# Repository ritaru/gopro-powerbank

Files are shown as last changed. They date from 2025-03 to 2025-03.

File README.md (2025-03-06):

## 5V 3A Capable Single 18650 Power Bank

The required components are as follows.

Parts are 2.0*1.2mm (2012 metric) if there is no further notation.

| Schematic Number | Value | Notes |
|:---:|:---:|:---:|
| BT1 / BT2 | Generic 18650 Holder | SMD / Through-Hole capable |
| U1 | TPS61022RWUR | Texas Instruments has the only capable IC |
| U2 | TP4056 | Generic TP4056 will work |
| U3 | S-8261 | DW01A also work |
| U4 | 8205A | Generic ones work |
| U5 | 8205A | Generic ones work |
| J1 | USB-C Receptacle | HRO Type, Recommending LCSC #C2765186 |
| R1 | 732k | Based on TPS61022 datasheet |
| R2 | 100k | Based on TPS61022 datasheet |
| R3 | 1.2k | Based on TP4056 datasheet |
| R4 | 1k | Based on TP4056 datasheet, decrease if not bright enough |
| R5 | 1k | Based on TP4056 datasheet, decrease if not bright enough |
| R6 | 1k | Based on DW01A datasheet, change if S-8261 is used |
| R7 | 100 | Based on DW01A datasheet, change if S-8261 is used |
| R8 | 5.1k | USB-C CC pin pull down |
| R9 | 5.1k | USB-C CC pin pull down |
| C1 | 10u / 10V | X5R, MLCC |
| C2 | 10u / 10V | X5R, MLCC |
| C3 | 0.1u / 50V | MLCC |
| C4 | 22u / 10V | X5R, MLCC |
| C5 | 22u / 10V | X5R, MLCC |
| C6 | 22u / 10V | X5R, MLCC |
| C7 | 0.1u / 50V | MLCC |
| C8 | 0.1u / 50V | MLCC |
| L1 | 1u | XAL7030-102MEC, TI reference design |
| D1 | Generic LED | STANDBY |
| D2 | Generic LED | CHARGING |
| D3 | TVS Diode | 5.6V Breakdown, SOD-323 |

## Side notes

- This is designed for Gopro Hero 9/10/11/12.
- Gopro Hero 9/10/11/12 requires a charger that is capable of delivering more than 10W(5V 2A) with no internal battery.
- I find this design to be also suitable for outdoor use when appropriate enclosure is added for a helmet mount.
- For copper weight on the PCB, it is 2oz minimum. (Due to limitation of L1 contacts on TPS61022)
- It automatically engages PFM(Pulse Frequency Modulation) when on low load. The MODE pin is pulled down.
- When not in use, please disconnect the battery. There is no onboard switch for on/off feature. (I might add this though)
- TP4056 happens to be quite hot when charging. Use separate charging tools (such as XTAR or Nitecore) for durability.
- I haven't built this yet, so additional features may be added later.

### AGPL v3.0 License
This repository is using AGPL v3.0.

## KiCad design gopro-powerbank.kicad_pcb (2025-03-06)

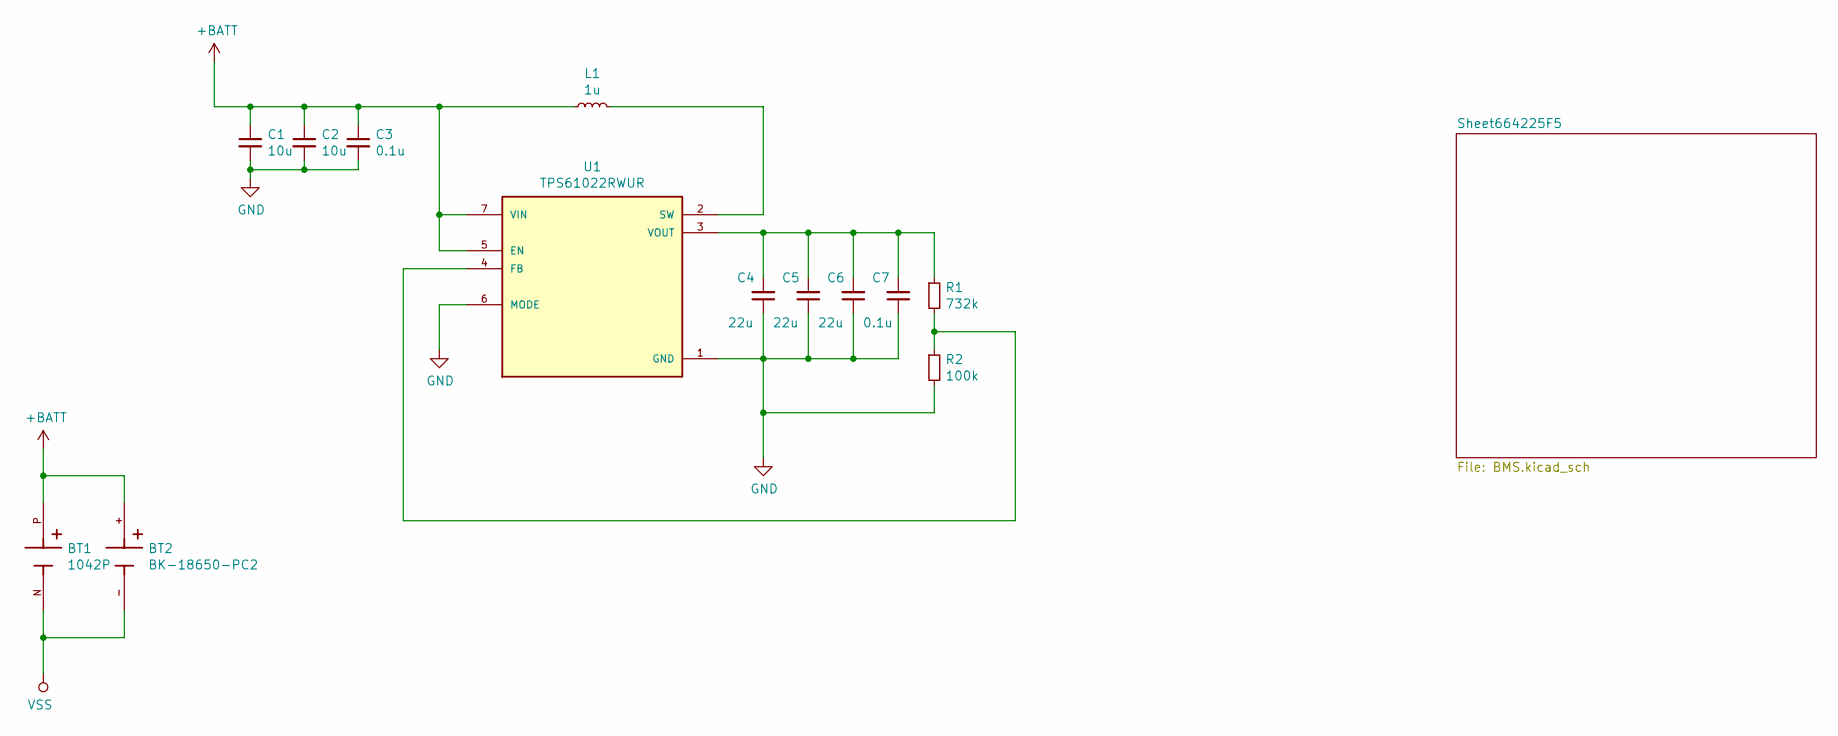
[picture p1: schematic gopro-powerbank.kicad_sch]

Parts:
BT1: 1042P; BAT_1042P; PARTREV E
BT2: BK-18650-PC2; BAT_BK-18650-PC2; PARTREV F
C1, C2: 10u; C_0805_2012Metric_Pad1.15x1.40mm_HandSolder
C3, C7: 0.1u; C_0805_2012Metric_Pad1.15x1.40mm_HandSolder
C4, C5, C6: 22u; C_0805_2012Metric_Pad1.15x1.40mm_HandSolder
L1: 1u; INDDFN750X750X310-2N
R1: 732k; R_0805_2012Metric_Pad1.15x1.40mm_HandSolder
R2: 100k; R_0805_2012Metric_Pad1.15x1.40mm_HandSolder
U1: TPS61022RWUR; CONV_TPS61022RWUR; PARTREV 4223724/C 02/2018

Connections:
+BATT: BT1.P, BT2.+, C1.1, C2.1, C3.1, L1.1, U1.5 (EN), U1.7 (VIN); also elsewhere on the board
GND: C1.2, C2.2, C3.2, C4.1, C5.1, C6.1, C7.1, R2.2, U1.1 (GND), U1.6 (MODE); also elsewhere on the board
unnamed: C4.2, C5.2, C6.2, C7.2, R1.1, U1.3 (VOUT)
unnamed: L1.2, U1.2 (SW)
unnamed: R1.2, R2.1, U1.4 (FB)
VSS: BT1.N, BT2.-; also elsewhere on the board

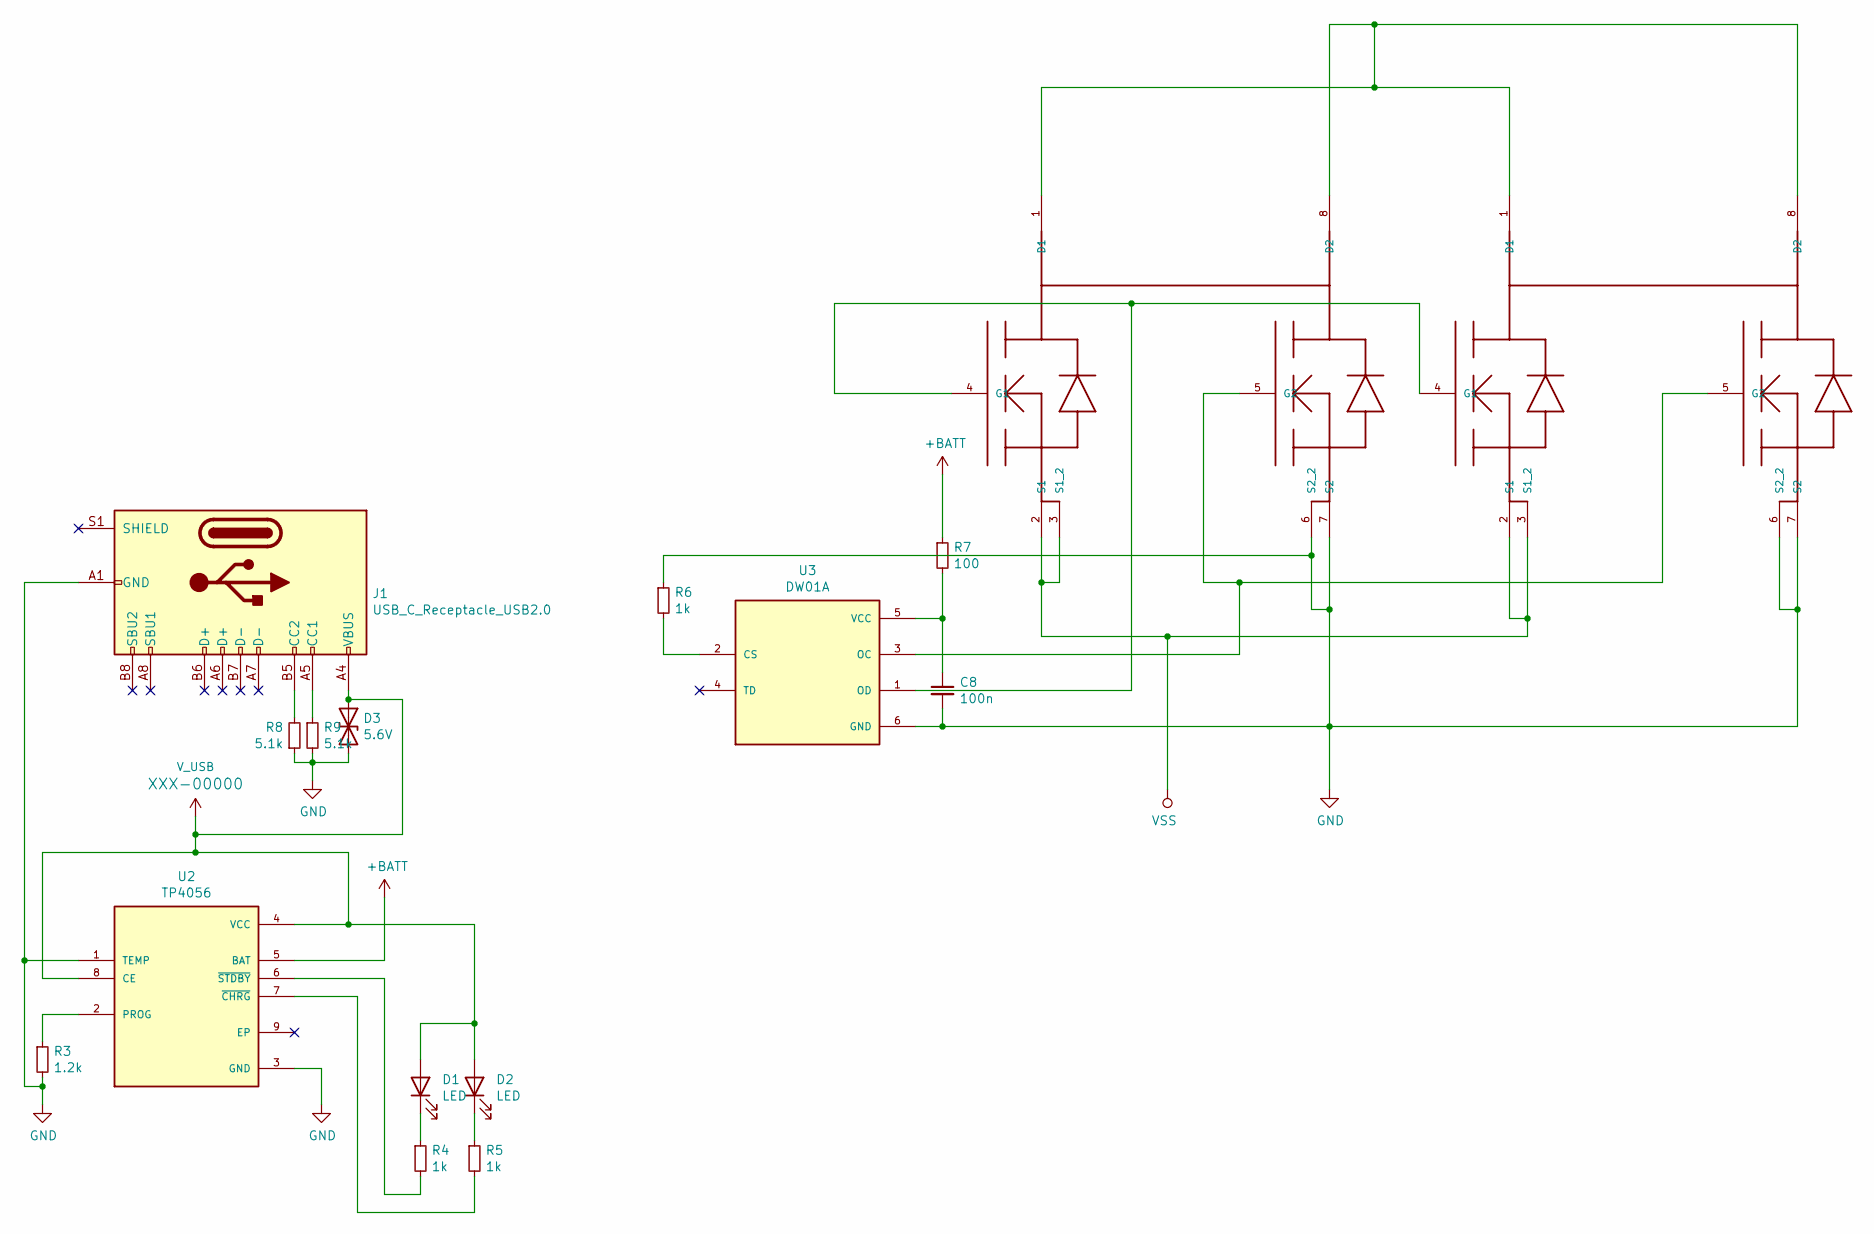
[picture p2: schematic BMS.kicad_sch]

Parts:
C8: 100n; C_0805_2012Metric_Pad1.15x1.40mm_HandSolder
D1, D2: LED; LED_0805_2012Metric_Pad1.15x1.40mm_HandSolder
D3: 5.6V; D_SOD-323_HandSoldering
J1: USB_C_Receptacle_USB2.0; USB_C_Receptacle_HRO_TYPE-C-31-M-12
R3: 1.2k; R_0805_2012Metric_Pad1.15x1.40mm_HandSolder
R4, R5, R6: 1k; R_0805_2012Metric_Pad1.15x1.40mm_HandSolder
R7: 100; R_0805_2012Metric_Pad1.15x1.40mm_HandSolder
R8, R9: 5.1k; R_0805_2012Metric_Pad1.15x1.40mm_HandSolder
U2: TP4056; SOP127P600X175-9N
U3: DW01A; SOT95P280X145-6N; PARTREV 1.8
U4, U5: 8205A; TSSOP8

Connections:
+BATT: R7.1, U2.5 (BAT); also elsewhere on the board
GND: C8.2, D3.2 (A2), J1.A1 (GND), J1.A12 (GND), J1.B1 (GND), J1.B12 (GND), R3.2, R6.1, R8.1, R9.2, U2.1 (TEMP), U2.3 (GND), U3.6 (GND), U4.6 (S2_2), U4.7 (S2), U5.6 (S2_2), U5.7 (S2); also elsewhere on the board
unnamed: C8.1, R7.2, U3.5 (VCC)
unnamed: D1.1 (K), R4.1
unnamed: D2.1 (K), R5.1
unnamed: J1.A5 (CC1), R9.1
unnamed: J1.B5 (CC2), R8.2
unnamed: R3.1, U2.2 (PROG)
unnamed: R4.2, U2.6 (~STDBY)
unnamed: R5.2, U2.7 (~CHRG)
unnamed: R6.2, U3.2 (CS)
unnamed: U3.1 (OD), U4.4 (G1), U5.4 (G1)
unnamed: U3.3 (OC), U4.5 (G2), U5.5 (G2)
unnamed: U4.1 (D1), U4.8 (D2), U5.1 (D1), U5.8 (D2)
VSS: U4.2 (S1), U4.3 (S1_2), U5.2 (S1), U5.3 (S1_2); also elsewhere on the board
V_USB: D1.2 (A), D2.2 (A), D3.1 (A1), J1.A4 (VBUS), J1.A9 (VBUS), J1.B4 (VBUS), J1.B9 (VBUS), U2.4 (VCC), U2.8 (CE)

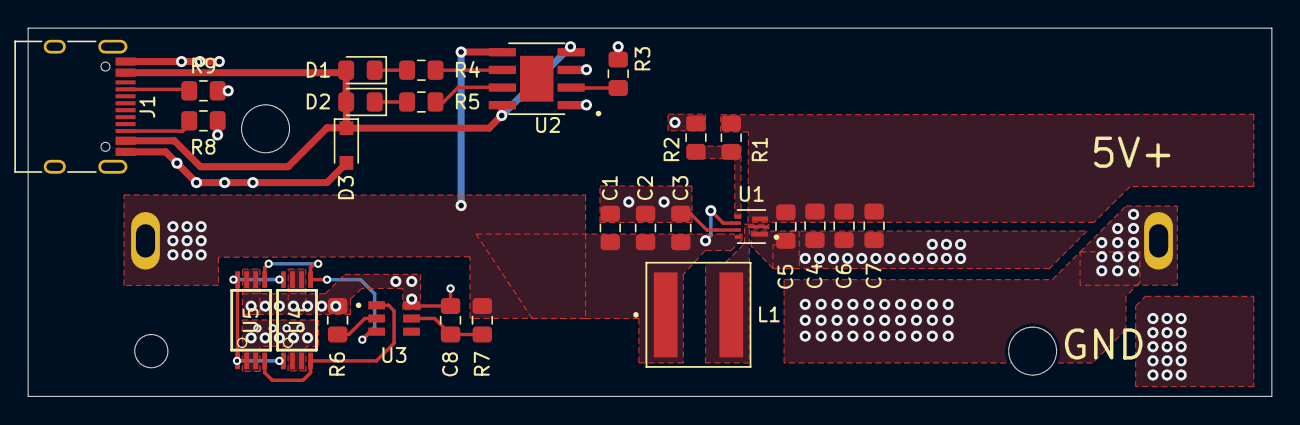
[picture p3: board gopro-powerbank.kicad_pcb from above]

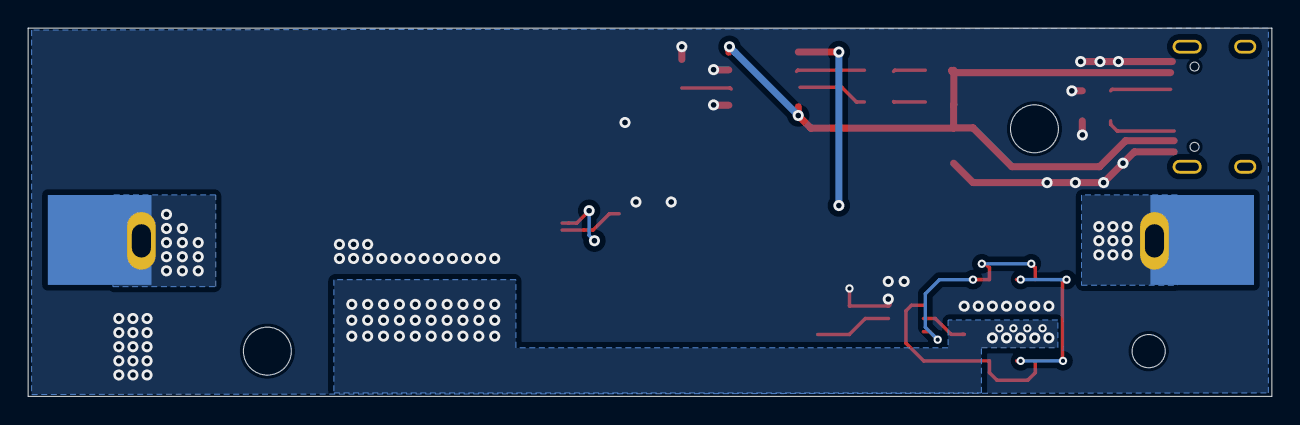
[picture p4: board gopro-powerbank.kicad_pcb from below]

Board: 2 copper layers, 89.5 x 26.5 mm, 29 parts (2 on the bottom side), 19 nets.

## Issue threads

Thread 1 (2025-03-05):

No gopro-powerbank.lib

haoyuanxu430, 2025-03-05:
Hi, I am interested in the design for bms. Could you please upload the library you used for schematic and pcb design? Currently, many parts are not loading in KiCAD.

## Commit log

2024-05-13 added readme
    [gopro-powerbank.kicad_pcb]
2025-03-06 added library and footprints
    [BMS.sch, gopro-powerbank.kicad_pcb, gopro-powerbank.sch]
2025-03-06 kicad version upgrade
    [gopro-powerbank.kicad_pcb]
2025-03-06 rescue symbols
    [BMS.kicad_sch, gopro-powerbank.kicad_sch]
